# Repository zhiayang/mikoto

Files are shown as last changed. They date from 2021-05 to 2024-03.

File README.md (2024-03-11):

# みこと

nRF52840 microcontroller, in a pro-micro footprint, inspired by the [nRFMicro](https://github.com/joric/nrfmicro) and [nice!nano](https://nicekeyboards.com/nice-nano).

**See [the changelog](./CHANGELOG.md) for the revision history (and compatibility)**

### picture

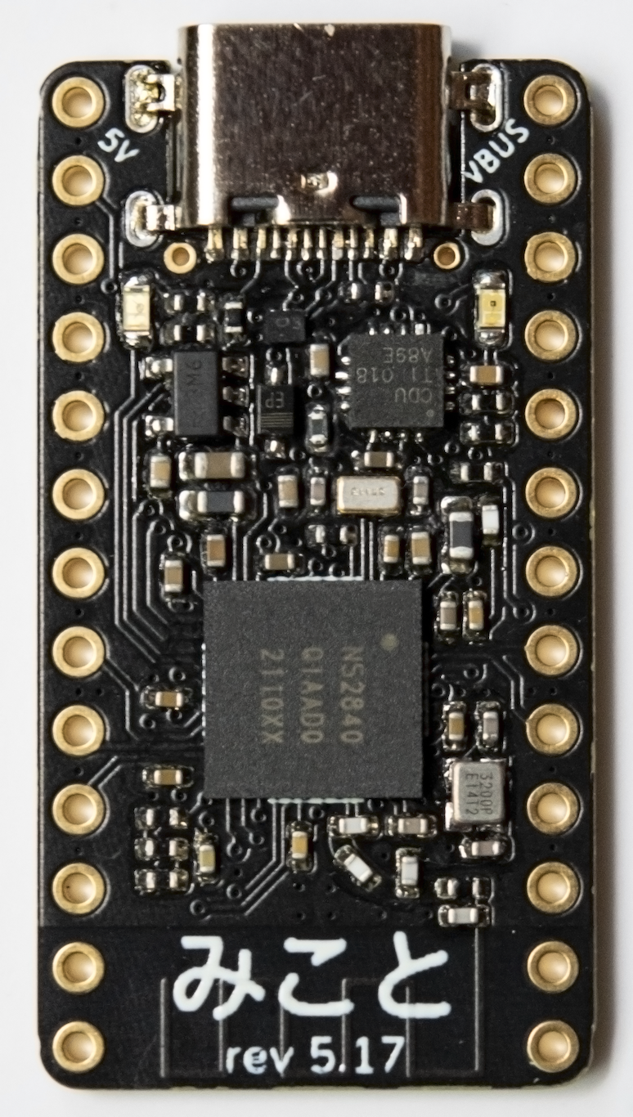
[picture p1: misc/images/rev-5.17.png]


### what

1. VDDH power path (5V USB power, and/or 3.7V Li-ion battery)
2. software controllable battery charge current (off, ~100mA, ~250mA, ~350mA)
3. ESD protection on USB lines, and 500mA fuse protection for VBUS and EXT_5V
4. "Bidirectional" power over EXT_5V

The charger IC is "software controlled"; there are two pins (P0.26 and P1.15) that can be toggled (for a total of 4 combinations) to control the charge current. If they are both high-Z (floated), is disabled.

There are also two additional through-holes (the small ones below the USB connector), marked **B** and **G** (on the back side); these are **B+** and **B-** respectively, in case you want to solder the battery leads directly to the board.

Note that the project files require KiCad 6.0.

### ext_5v

The EXT_5V pin acts both as a power input and a power output; normally it is an input. When VBUS is high (ie. USB is connected), it will output VBUS (minus a schottky drop, ~0.3V).

EXT_5V is connected to the battery charger, so if you wire your TRRS (for split keyboards) to it (instead of a 3.3V VCC line), you can charge the battery on both halves by only plugging in one half to USB.

### production & assembly

Since the design contains a controlled-impedance trace (namely the antenna feed), it is specific to a given stackup from a given
manufacturer. The current design files are optimised for JLCPCB's 1.6mm, 4-layer 7628 stackup.

**read**: if you choose to use a different (1) board thickness, (2) manufacturer, or (3) stackup, you ***must*** modify the design
accordingly to change the antenna feed (either trace width, plane separation, or both). The antenna feed uses a grounded coplanar waveguide design.

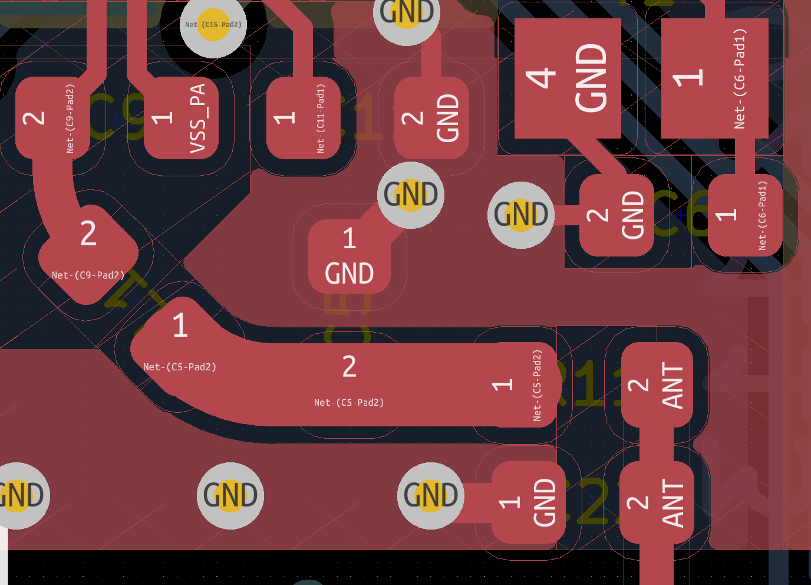
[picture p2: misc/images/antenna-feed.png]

<p align="center">Figure 1: the antenna feed</p>

The PCB *should* be manufactured with an ENIG surface finish, but it has been tested with HASL boards (run a solder wick over the pads first). All components are 0402 (1005 metric) or larger, and can be placed by hand without magnification. A stencil is mandatory — get a 100µm (0.1mm) thick one.

It's a good idea to get an electropolished stencil if you want to paste more than one board at a time, otherwise you will probably need to completely clean out the stencil before pasting another board.

All prototypes are assembled with Chipquik SMD291AX T4 solder paste.

There's no "component silkscreen" on the board except 4 lines to align the nRF chip, so use [`ibom.html`](./misc/ibom.html) while placing parts. It is generated using KiCad's excellent [Interactive BOM](https://github.com/openscopeproject/InteractiveHtmlBom) plugin.

### software

ZMK now has support for mikoto, as of [this PR](https://github.com/zmkfirmware/zmk/pull/985), and so does the *Adafruit nRF52 Bootloader*, as of [this PR](https://github.com/adafruit/Adafruit_nRF52_Bootloader/pull/230). Thanks to @mrninhvn for both of those. A binary version of the bootloader (0.6.3) can be found in `misc/bootloaders/`.

### license

Licensed under the Apache 2.0 license, see [LICENSE](./LICENSE).

If you encounter any problems, feel free to open an issue on this repo. However, I am *not obligated* to provide any support, and you undertake any assembly/manufacturing/purchasing **at your own risk**.

> on an **AS IS** BASIS, **WITHOUT WARRANTIES** OR CONDITIONS OF ANY KIND, either express or implied, including, without limitation, any warranties or conditions of TITLE, NON-INFRINGEMENT, MERCHANTABILITY, or FITNESS FOR A PARTICULAR PURPOSE.

> In **no event** and under no legal theory, ..., shall any Contributor be liable to You for damages, including any direct, indirect, special, incidental, or consequential damages of any character arising as a result of this License or out of the use or inability to use the Work.

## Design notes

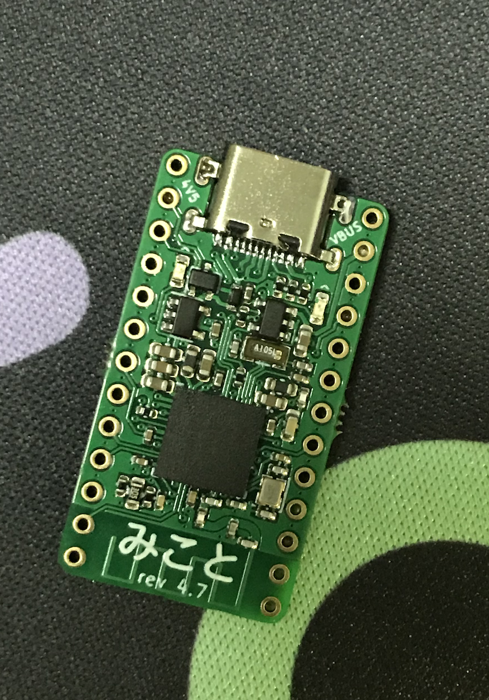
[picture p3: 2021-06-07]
misc/images/rev-4.7.png

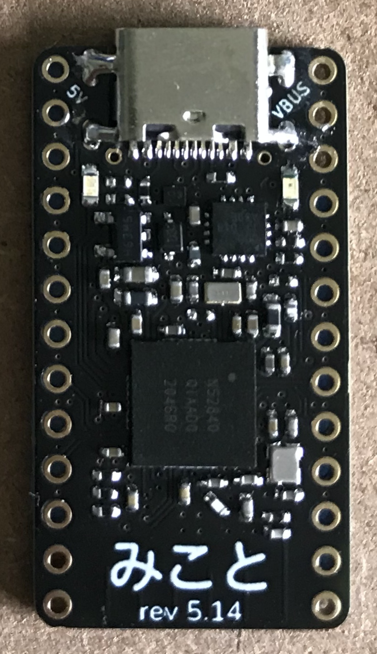
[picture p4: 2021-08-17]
misc/images/rev-5.14.png

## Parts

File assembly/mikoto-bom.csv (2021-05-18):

Comment | Designator | Footprint | LCSC Part #
4.7uF Unpolarized capacitor, small symbol | C1,C13,C14,C20,C21,C25 | C_0603_1608Metric | C19666
100nF Unpolarized capacitor, small symbol | C2,C3,C4,C10 | C_0402_1005Metric | C1525
1pF Unpolarized capacitor, small symbol | C5,C9 | C_0402_1005Metric | C1550
10pF Unpolarized capacitor, small symbol | C6,C7 | C_0402_1005Metric | C32949
1uF Unpolarized capacitor, small symbol | C8,C15,C23,C24 | C_0402_1005Metric | C52923
100pF Unpolarized capacitor, small symbol | C11 | C_0402_1005Metric | C1546
1nF Unpolarized capacitor, small symbol | C12 | C_0402_1005Metric | C1523
47nF Unpolarized capacitor, small symbol | C16 | C_0603_1608Metric | C1622
15pF Unpolarized capacitor, small symbol | C17,C18 | C_0402_1005Metric | C1548
10nF Unpolarized capacitor, small symbol | C19 | C_0402_1005Metric | C15195
1.5pF Unpolarized capacitor, small symbol | C22 | C_0402_1005Metric | C1552
BLUE Light emitting diode, small symbol | D1 | LED_0603_1608Metric | C72041
MSK4010 Schottky diode, small symbol | D2 | D_SOD-523 | C345958
ORANGE Light emitting diode, small symbol | D3 | LED_0603_1608Metric | C2286
logo_front Mounting Hole without connection | DUMMY1 | mikoto-logo
logo_back Mounting Hole without connection | DUMMY2 | mikoto-logo
mousebite_left Mounting Hole without connection | DUMMY3 | mouse-bite-2mm-slot-one-sided
mousebite_right Mounting Hole without connection | DUMMY4 | mouse-bite-2mm-slot-one-sided
USB_C_Receptacle_USB2.0 | J1 | USB-C_C168688
Conn_01x01 Generic connector, single row, 01x01, script generated (kicad-library-utils/schlib/autogen/connector/) | J2,J3 | 1pin_conn
3.9nH Inductor, small symbol | L1 | L_0402_1005Metric | C14033
15nH Inductor, small symbol | L2 | L_0402_1005Metric | C27143
10uH Inductor, small symbol | L3,L4 | L_0603_1608Metric | C1035
Net-Tie_2 Net tie, 2 pins | NT1 | net-tie-2-tiny
Net-Tie_2 Net tie, 2 pins | NT2,NT3 | net-tie-2-0.3mm
DMP2165UW P-MOSFET transistor, gate/source/drain | Q2 | SOT-323_SC-70 | C388477
1M Resistor, small symbol | R3 | R_0402_1005Metric | C26083
10M Resistor, small symbol | R4 | R_0402_1005Metric | C26082
1k Resistor, small symbol | R5,R8 | R_0402_1005Metric | C11702
100k Resistor, small symbol | R6 | R_0402_1005Metric | C25741
10k Resistor, small symbol | R7 | R_0402_1005Metric | C25744
5.1k Resistor, small symbol | R9,R10 | R_0402_1005Metric | C25905
3M Resistor, small symbol | R11 | R_0603_1608Metric | C23156
TestPoint test point | TP1,TP2,TP3 | TestPoint_Pad_1.0x1.0mm
TestPoint test point | TP4 | circular-pad-0.3mm
nRF52840 Multiprotocol BLE/ANT/2.4 GHz/802.15.4 Cortex-M4F SoC, AQFN-73 | U1 | Nordic_AQFN-73-1EP_7x7mm_P0.5mm | C190794
TP4054 Single cell, Li-Ion/Li-Po charge management controller, 4.20V, Tri-State Status Output, in SOT23-5 package | U2 | SOT-23-5 | C32574
AP2112K-3.3 600mA low dropout linear regulator, with enable pin, 3.8V-6V input voltage range, 3.3V fixed positive output, SOT-23-5 | U3 | SOT-23-5 | C51118
ProMicro_2 | U4 | akami-pins
32MHz Four pin crystal, GND on pins 2 and 4, small symbol | Y1 | Crystal_SMD_2016-4Pin_2.0x1.6mm | C254298
32.768 kHz Two pin crystal, small symbol | Y2 | Crystal_SMD_3215-2Pin_3.2x1.5mm | C32346

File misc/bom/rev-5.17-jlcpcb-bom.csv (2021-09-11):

Comment | Designator | Footprint | LCSC Part #
4.7uF Unpolarized capacitor, small symbol | C1,C13,C14,C20,C24,C25,C26 | Capacitor_0402_1005M-nosilk | C23733
100nF Unpolarized capacitor, small symbol | C2,C3,C4,C10 | Capacitor_0402_1005M-nosilk | C1525
1pF Unpolarized capacitor, small symbol | C5,C9 | Capacitor_0402_1005M-nosilk | C1550
15pF Unpolarized capacitor, small symbol | C6,C7,C17,C18 | Capacitor_0402_1005M-nosilk | C1548
1uF Unpolarized capacitor, small symbol | C8,C15,C23 | Capacitor_0402_1005M-nosilk | C52923
100pF Unpolarized capacitor, small symbol | C11 | Capacitor_0402_1005M-nosilk | C1546
1nF Unpolarized capacitor, small symbol | C12 | Capacitor_0402_1005M-nosilk | C1523
47nF Unpolarized capacitor, small symbol | C16 | Capacitor_0402_1005M-nosilk | C26403
10nF Unpolarized capacitor, small symbol | C19 | Capacitor_0402_1005M-nosilk | C15195
10uF Unpolarized capacitor, small symbol | C21 | Capacitor_0603_1608M-nosilk | C19702
1.5pF Unpolarized capacitor, small symbol | C22 | Capacitor_0402_1005M-nosilk | C1552
BLUE Light emitting diode, small symbol | D1 | LED_0603_1608Metric | C72041
ORANGE Light emitting diode, small symbol | D3 | LED_0603_1608Metric | C72038
PMEG4010CEJ Schottky diode, small symbol | D5 | D_SOD-323F-nosilk | C50704
500mA hold Resettable fuse, polymeric positive temperature coefficient, small symbol | F1 | Fuse_0402_1005Metric | C206938
USB_C_Receptacle_USB2.0 | J1 | USB-C_C168688 | C168688
3.9nH Inductor, small symbol | L1 | Inductor_0402_1005M-nosilk | C14033
15nH Inductor, small symbol | L2 | Inductor_0402_1005M-nosilk | C27143
10uH Inductor, small symbol | L3,L4 | Inductor_0603_1608M-nosilk | C1035
Net-Tie_2 Net tie, 2 pins | NT1 | net-tie-2-tiny
3.9k Resistor, small symbol | R1 | Resistor_0402_1005M-nosilk | C51721
2M Resistor, small symbol | R2,R3,R12 | Resistor_0402_1005M-nosilk | C138014
10M Resistor, small symbol | R4 | Resistor_0402_1005M-nosilk | C26082
1.5k Resistor, small symbol | R5 | Resistor_0402_1005M-nosilk | C25867
10k Resistor, small symbol | R6,R7,R8 | Resistor_0402_1005M-nosilk | C25744
5.1k Resistor, small symbol | R9,R10 | Resistor_0402_1005M-nosilk | C25905
0R Resistor, small symbol | R11 | Resistor_0402_1005M-nosilk | C17168
nRF52840 Multiprotocol BLE/ANT/2.4 GHz/802.15.4 Cortex-M4F SoC, AQFN-73 | U1 | AQFN-73-1EP_7x7mm_P0.5mm_NRF52840-custom | C1851953
BQ24075/9 USB-Friendly Li-Ion Battery Charger and Power-Path Management | U2 | VQFN-16-1EP_3x3mm_P0.5mm_EP1.6x1.6mm | C15464
XC6220B331MR 1A, Low Drop-out Voltage Regulator, Fixed Output 3.3V, SOT-23-5 | U3 | SOT-23-5 | C86534
mikoto-pins | U4 | mikoto-pins
ESDR0502NMUTAG | U5 | UDFN-6_1.2x1.0mm_P0.4mm | C327480
32MHz Four pin crystal, GND on pins 2 and 4, small symbol | Y1 | Crystal_SMD_2016-4Pin_2.0x1.6mm | C255896
32.768 kHz Two pin crystal, small symbol | Y2 | Crystal_SMD_2012-2Pin_2.0x1.2mm | C93231

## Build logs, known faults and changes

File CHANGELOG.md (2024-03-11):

# changelog

Note that numbers are skipped arbitrarily based on my whims and fancies.

## revision 7.2 (untested)

Previous revision: 7.1

Compatibility:

- Pinout identical to 6.3
- New stencil required (different from 7.1)

Changes:

1. remove I2C pullups from MAX17048 chip; they were frying the MCU IO pins
2. shrink LEDs to 0402 size
3. add solder points for metal can

## revision 7.1 (do not build -- broken)

Previous revision: 6.3

Compatibility:

- Pinout identical to 6.3
- New stencil required

Changes:

1. add on-board MAX17048 fuel gauge IC for battery monitoring

## revision 6.3

Previous revision: 6.1

Compatibility:

- (Slightly) incompatible pinout: `VDDH` pin (top right) changed to `VDD`
- Stencil / position / parts compatible with 5.17+
- Underside pads compatible with 6.1

Changes:

1. Change the `VDDH` extra pin to be `VDD` instead; note that it's usually an output, and should only draw a maximum of 25mA (less when transmitting!)
2. Fiddle slightly with the antenna layout (with ref. to the nRF52840 Dongle from Nordic) even though I don't know what I'm doing
3. Adjust trace routing around the antenna feed to improve ground plane coverage

## revision 6.1

Previous revision: 5.20

Compatibility:

- Incompatible pinout, bottom pad layout for USB changed (SWD pad positions unchanged).
- Stencil / position / parts compatible with revisions 5.17 - 5.20.

Changes:

1. Changed `P1.00` to `P1.08` (still high drive)
2. Exposed the old `P1.00` as an `SWO` pad instead (useful for debug trace output)
3. Changed the `VBUS` pin to expose `VDDH` instead
4. `VBUS` exposed as an underside pad

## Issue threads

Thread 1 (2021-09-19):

can it use nice！nano firmware directly？

SAIXX, 2021-09-19:
If there are some differences with that when re-flash the bootloader?

zhiayang, 2021-09-19:
you can use the nice!nano v2 bootloader directly. firmware-wise, there is no official ZMK shield.

Closed 2021-10-05.

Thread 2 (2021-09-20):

Why there's a voltage regulator in the design?

marekpiechut, 2021-09-20:
Hi.

Sorry for opening an issue, but found no better place to get in touch with you.

I'm studying the design, and while most of the stuff makes sense for me, I don't get why do you have an external voltage regulator there. It seems that you're powering the battery charger module directly from USB and then connect it directly to VDDH on the MCU. It looks like regulated voltage is only being used to output it on pin 22 of Pro-Micro compatible pins and it's not really needed for the board to work.

Am I right, or am I missing something?
Thanks for help.

zhiayang, 2021-09-21:
yes, that's right. the LDO is only to power external stuff (eg. LEDs, displays, etc.) on whatever you attach the mikoto to, and not used for anything on-board.

Closed 2021-09-21.

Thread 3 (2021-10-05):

Hi , has you simulated the antenna signal  in HFSS ?

xiaoquanaa, 2021-10-05:
Hi , has you simulated the antenna signal  in HFSS ?

zhiayang, 2021-10-05:
no, i have not.

xiaoquanaa, 2021-10-05:
so does it works well as a keyboard mcu?

xiaoquanaa, 2021-10-05:
> no, i have not.

so does it works well as a keyboard mcu?

zhiayang, 2021-10-05:
the bluetooth radio works well. i have not written the firmware for it yet, but you can get zmk working without too much effort.

xiaoquanaa, 2021-10-07:
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
Hi , i can't understand that why p0.14 and p0.16 i named "reset" , isn't a default reset pin p0.18?

Closed 2021-10-12.

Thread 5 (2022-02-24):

BLE has no service

ImMrMa, 2022-02-24:
Hi, thank you so much for sharing your mikoto repo, I printed the mikoto pcb and loader zmk software in the pcb. But I can't connect the hid ble sevice, seems the ble signal has no advertised service

zhiayang, 2022-02-25:
i can't tell if this is a hardware problem or a software issue (with zmk). are you able to load up a simpler firmware (eg. just something that makes a BLE beacon) and see if the antenna works?

check the component placement and soldering as well. which revision did you print?

ImMrMa, 2022-02-25:
I use the revision 5.20 for print. And flash the bootloader and zmk you mentioned. Are there any recommended programs to flash just for test the ble.

zhiayang, 2022-02-25:
you can get get bluemicro board support package for nrf52840, and use something like this https://learn.adafruit.com/bluefruit-nrf52-feather-learning-guide/advertising-beacon to test it out

ImMrMa, 2022-02-26:
I recheck my bom list. found that I use 32mhz 8pf as the crystal rather than 32mhz 12.5pf you used. Is this the main reason？I try to replace a 12.5pf crystal on it.

zhiayang, 2022-02-26:
that could be the possible culprit; afaik the HF crystal is used for timing bluetooth packets, so if the capacitance is out of spec then the frequency could deviate enough that bluetooth won't work.

you can either replace the crystal, or replace the load capacitors with something that'll work for a 8pf crystal.

ImMrMa, 2022-03-05:
After replace the crystal, I finally successfully connect to the board by ble!
Thanks for you help !!!

Closed 2022-03-05.

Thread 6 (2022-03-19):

What to choose for layer stackups and other choices for PCB manufacturing?

Ardakilic, 2022-03-19:
Hello,

I want to try this board, but I'm lost at ordering step.

While ordering from JLCPCB, what do I have to choose for these layer stackup choices?

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

An example screenshot or list of choices would have been awesome. Even with providing the stackups, I can't enable the SMT assembly, it's telling me to reset the order.

Thanks in advance!

zhiayang, 2022-03-20:
L1 = F_Cu
L2 = In1_Cu
L3 = In2_Cu
L4 = B_Cu

Stackup = JLC7628

As for assembly, I don't know if they have stock of all the chips (notably the charging IC and MCU itself). Last time I checked you're also limited to green PCBs for 4-layer assembly.

Ardakilic, 2022-03-20:
Thanks for this. Finally I could pass these parameters. I just wish JLC did not cost $265 for 5 PCB's BOM, and this is even missing nRF52840 itself!

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

I'll definitely buy the PCBs and stencil, and source the parts in the future by myself.

Thanks again!

zhiayang, 2022-03-21:
heck, that is really expensive. it'll be very hard to place/solder the MCU (basically impossible) once the other parts are populated though, so getting it assembled at JLC is usually all-or-nothing.

Closed 2022-03-20.

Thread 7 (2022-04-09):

why short reset pin with a GPIO pin?

DoudouMee, 2022-04-09:
- I dont understand why connect reset pin (P0.18/RESET) to P0.14 and P0.16. These 3 GPIO are completely shorted together.
- If I change the schematic and free them up, can I use they 3 pins as GPIO without short P0.18/RESET to any other pin?

> 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

zhiayang, 2022-04-09:
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

there is no other way to get the reset pin out from under the chip.

DoudouMee, 2022-04-09:
> 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
>
> there is no other way to get the reset pin out from under the chip.

soga! So, in fact I dont need a high voltage on  (P0.18/RESET) when this Soc starting up?

zhiayang, 2022-04-09:
no, the reset pin has an internal pullup on nRF chips.

DoudouMee, 2022-04-10:
I see, thanks a lot.

Closed 2022-04-10.

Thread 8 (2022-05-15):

board not work after flashing zmk uf2

ImMrMa, 2022-05-15:
Hello, Zhiayang
I have some confuse in develop my own board.
I follow your schema designed my board with fpc interface and ceramic anatenna.
I successfully tested the board in circuit python that both BLE and HID are work well with your bootloader.
But after flash your mikoto zmk build uf2 file, my computer couldn't find the hid keyboard signal through usb.
Could you give me some advice on problems (like def in pins or others) may cause the zmk program not working.
More details:
when I set bootloader mode or flash the circuit python uf2, the crystal has 0.869v.
After I flash the zmk uf2, the crystal only has 0.15~0.3v.
It make me confused.
Best Wishes

ImMrMa, 2022-05-15:
Ok, finally I found that I lost a 10uH inductance in the schema.
After I disable the dcdc mode in zmk, the program work well.
Thank you so much!

Closed 2022-05-15.

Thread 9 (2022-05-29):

Any specific reason for the incompatible pinout?

Miigon, 2022-05-29:
It seems like the current pinout of mikoto isn't really compatible with nice!nano or promicro-based keyboard pcb. The top most pins on the left and right side are EXT_5V and VDD_NRF instead of B- and B+, and VBAT is connected to where RAW would be on a pro micro. I wonder is this a deliberate design choice?

Because of the different battery pinout, mikoto can't really be used as a drop-in replacement for a nice!nano. Instead requiring the keyboard pcb to be specifically designed for and only for mikoto. (aka connecting battery to RAW). But that would render the keyboard incompatible with any other pro micro compatible microcontroller since most controllers connect VBUS to RAW, which meant they will SEND 5V DIRECTLY TO THE BATTERY if used on a pcb designed for mikoto.

(Unfortunately I have to find out about the incompatible pinout the hard way by distroying 2 of my mikoto boards (dead nrf52840) because the battery tried to send too high of a voltage to what it thought was B+ but actually is VDD_NRF. 😢)

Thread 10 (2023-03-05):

Device don't connect

admfgonzalez, 2023-03-05:
Hi zhiayang, first of all thank you very much for sharing your design with the community :). I sent to make some mikoto 6.3 to JLCPCB and they finally arrived, but I can't configure them, I may have done something wrong in the order process, especially with the orientation of the components. I'm not very good with electronics, could you help me identify what I did or what I'm doing wrong? Thank you very much in advance for your help. The microcontroller
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

zhiayang, 2023-05-25:
Sorry the super delayed response. Unfortunately I can't really help with this, it might be a manufacturing issue

Tworck, 2023-12-12:
Hey @admfgonzalez

Ultimately we are unsure what the problem is. The yellow light is constantly on and no connection to the microcontroller is made via usb

Did you figure out the issue to your problem. We believe that we have the same issue.

One thing that we notices is the orientation of the Y1 Oscillator.

We also used
https://www.farnell.com/datasheets/1562852.pdf

which states that connector 2 and connector 4 should be connected to GND. Which seems to be correct for the component we used. see image.

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

Kicad shows it in the same way.

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

So technically this should be correct. Maybe the issue is somewhere else.

zhiayang, 2023-12-13:
does the board show up over SWD? there's solder pads on the back you can use to connect to a stlink, and maybe try flashing firmware/bootloader with adafruit-nrfutil or openocd.

if it shows up over SWD, i would check the usb data lines for shorts (there's pads on the back too in case the connector pins are too small).

actually -- you guys *did* flash the bootloader, right? I don't think the usb connection will do anything (certainly it won't show up as a usb drive) until you do.

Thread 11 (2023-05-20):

Battery charging

djbutler, 2023-05-20:
I am trying to use Mikoto with a 3.7V 400mAh lithium ion polymer battery (https://www.adafruit.com/product/3898). I am setting the charging current to 100mA in software. But charging does not seem to work correctly: as I understand it, the battery is supposed to charge to about 4.2V, but it often gets stuck between 3V and 3.5V. It seems like perhaps the precharge phase is working, but not the fast charge phase. (See: https://www.ti.com/lit/ds/symlink/bq24075.pdf).

Is there a battery that is known to charge correctly with this circuit?

zhiayang, 2023-05-25:
I've only used no-name batteries from aliexpress, and they appear to work from my own testing. Are you setting the charge current via the driver in ZMK?

djbutler, 2023-05-28:
I'm actually running the `nice!nano` build of CircuitPython, and just setting pins P0.26 and P1.15 manually with `digitalio.DigitalInOut`:

```
en1 = digitalio.DigitalInOut(board.P0_26)
en1.direction = digitalio.Direction.OUTPUT
en1.value = False

en2 = digitalio.DigitalInOut(board.P1_15)
en2.direction = digitalio.Direction.INPUT
en2.pull = None
```

My understanding was that setting a pin as an input would produce a high-impedance state. But perhaps I'm doing this incorrectly.

Thanks for your feedback.

zhiayang, 2023-06-10:
yes, this should have worked. I'm not sure why it's not working, though. It might be some incompatibility somewhere, but I can't really help with just this much to go on.

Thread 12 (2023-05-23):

Wasn't sure how to reach out;

WainingForests, 2023-05-23:
Hey! I'm looking to mesh this design into something that incorporates JST SH connectors. I have a reasonably mediocre understanding of pcb design especially when it comes to signaling design.
Headers should be easy enough.

What I don't know if I can do for sure is if I can pull out 1 or 2 more extra pins. It looks like I "might" be able to pull them out via one of the internal layers. But I realize there is alot of considerations going on with your design and I don't want to end up breaking things more than I'm helping them.

Thoughts?

zhiayang, 2023-05-25:
Extra pins as in from the nRF chip itself? I'm not sure if there's space for that, but feel free to try. As for design considerations:

1. try not to split the ground plane on layers 2 and 3, because there isn't enough space for too many stitching vias
2. I can't remember if there's a power plane on layer 3 under the chip itself; if there is, then you definitely don't want to split it. The alternative is to get rid of the plane (if it exists) and just route power manually with thick traces.
3. As long as the modifications don't go near the antenna area, it should be fine :D

WainingForests, 2023-05-30:
Thanks by the way for the response! I've been "trying" and seem reasonably successful! I did have one question. Can you think of a way to have 3.3v output from battery that CAN'T be shut of by pin13?

I'd like to be able to toggle LEDS while not killing a trackball / trackpad / Shift register.

zhiayang, 2023-06-10:
Probably not, if it needs to be exactly 3.3v

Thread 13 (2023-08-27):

resistor R12 (2M) does not appear in file gerber

hvuitsme, 2023-08-27:
I checked that the Top designator part doesn't show the 2M(R12) resistor and I can't fix it

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

hvuitsme, 2023-08-27:
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

zhiayang, 2023-08-28:
since I did not provide the BOM and pick-and-place file (BOM/CPL), I don't think I can help you here.

hvuitsme, 2023-08-29:
I got the prototype in your repository
[mikoto-top-pos.csv](https://github.com/zhiayang/mikoto/files/12459930/mikoto-top-pos.csv)

Bomb file is still the same with this pos file

zhiayang, 2023-08-29:
how did you generate this file? some of the parts (like R12) are missing rotation values. that seems to be the problem.

cscott, 2024-02-07:
You should probably use the JLC Fabrication Toolkit plugin, available from KiCad's plug-in manager, to generate the production files.

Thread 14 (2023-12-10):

Questions about the power path

pymo, 2023-12-10:
Hi, sorry for raising an issue for this topic, but I don't find other ways to reach out.

I am making a keyboard PCB with the WCH CH582F chip, and I find your schematic a good reference for the power path part. However, there are some design questions I hope you can help me understand:

1. You seem to replace the TP4054+LDO with the BQ24075 in later revisions, what is the consideration? My MCU is 3.3V so I want to go with the TP4054+LDO solution, but I don't know if there are any disadvantages of it.

2. How necessary are the ESD Protection Diodes on D+/D-? Did you add them because you see damages happening without it?

3. You seem to replace the Schottky barrier diode from PMEG2010AEB to PMEG4010CEJ, what is the consideration? Is it OK to use a 1N5819WS instead?

Thanks in advance!

zhiayang, 2023-12-11:
1. the nrf52840 can do HV mode which uses the internal DC-DC voltage converter, which is more efficient than an LDO so in theory saves a bit of battery. otherwise you'd have to use LDO to step 3.7v battery to 3.3v.
2. just in case. it's the most frequently "touched" part, feels weird not to have esd
3. 2010 was too small (SOD523) for my old eyes, 4010 has SOD323 which is a little bigger.  i just chose a diode with a small Vf drop.

pymo, 2023-12-11:
Thanks a lot! Those answers are very helpful!

Closed 2023-12-11.

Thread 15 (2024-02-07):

PCB thickness

cscott, 2024-02-07:
The README says:
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

And indeed you specify the manufacturer and stackup -- but I don't think the README ever explicitly specifies the correct board thickness to use?  Reading between the lines (and looking at the KiCad setup) it /seems/ to be the "standard" 1.6mm board thickness, but it would be nice to explicitly say so in the README (if that's right).

Thanks so much for your board!  I'm hacking on it to use for a Ploopy Mini trackball, and it's a great timesaver to have working KiCad files for start with.

zhiayang, 2024-02-07:
oh, yep -- it's meant to be 1.6mm. I'll add that, thanks!

Closed 2024-02-07.

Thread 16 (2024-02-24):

Changelog for 7.1

alexmaloteaux, 2024-02-24:
Hi
Is there any relevant changelog for 7.1 , compared to 6.3 ?
Thanks

zhiayang, 2024-02-26:
thanks for reminding me, i'll update the doc in the next few days. the main difference is the on-board fuel gauge ic.

zhiayang, 2024-03-05:
welp, i screwed up rev 7.1, so the changelog isn't important.

zhiayang, 2024-03-11:
updated

Closed 2024-03-11.

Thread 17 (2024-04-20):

Can not use KiKit automation

ton-im, 2024-04-20:
If use KiKit automation , KiCAD will show error as pic1 .
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
Because of the file mikoto.kicad_pcb have 6 wrong lines , 11335-11340 . These lines add nothing .
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
Delete these lines , KiKit will work well .

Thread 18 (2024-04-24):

pinmux.c, purpose of gpio_pin_set(p0,3,0)

yangxing844, 2024-04-24:
hi, in the pinmux.c which is the file source used to control the charge current, what is the purpose of gpio_pin_set(p0,3,0), in the schematic, the pin is not connected, why would we do anything with it?

yangxing844, 2024-04-24:
sorry, that was a mistake of global substitute, closing now

Closed 2024-04-24.

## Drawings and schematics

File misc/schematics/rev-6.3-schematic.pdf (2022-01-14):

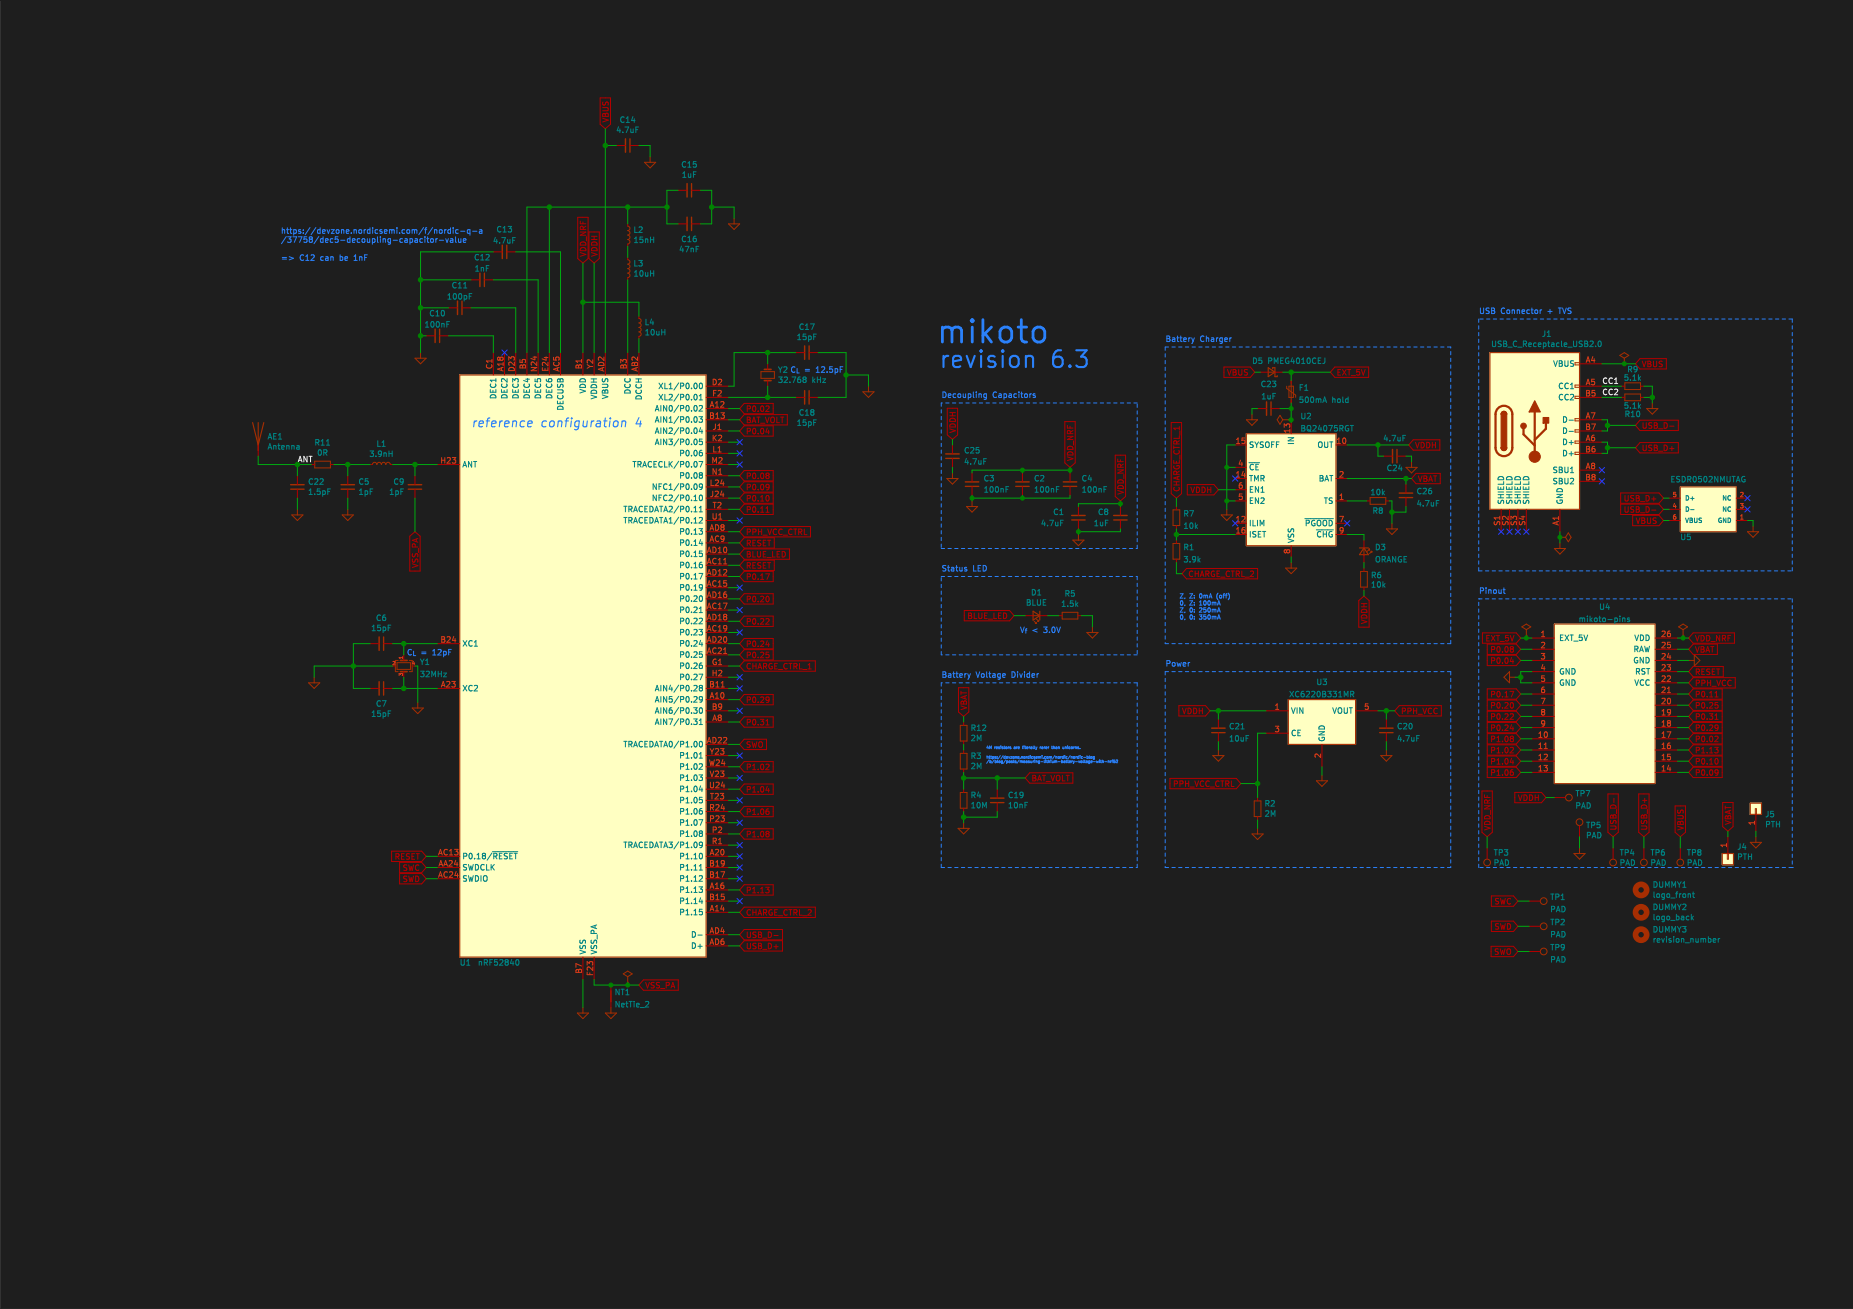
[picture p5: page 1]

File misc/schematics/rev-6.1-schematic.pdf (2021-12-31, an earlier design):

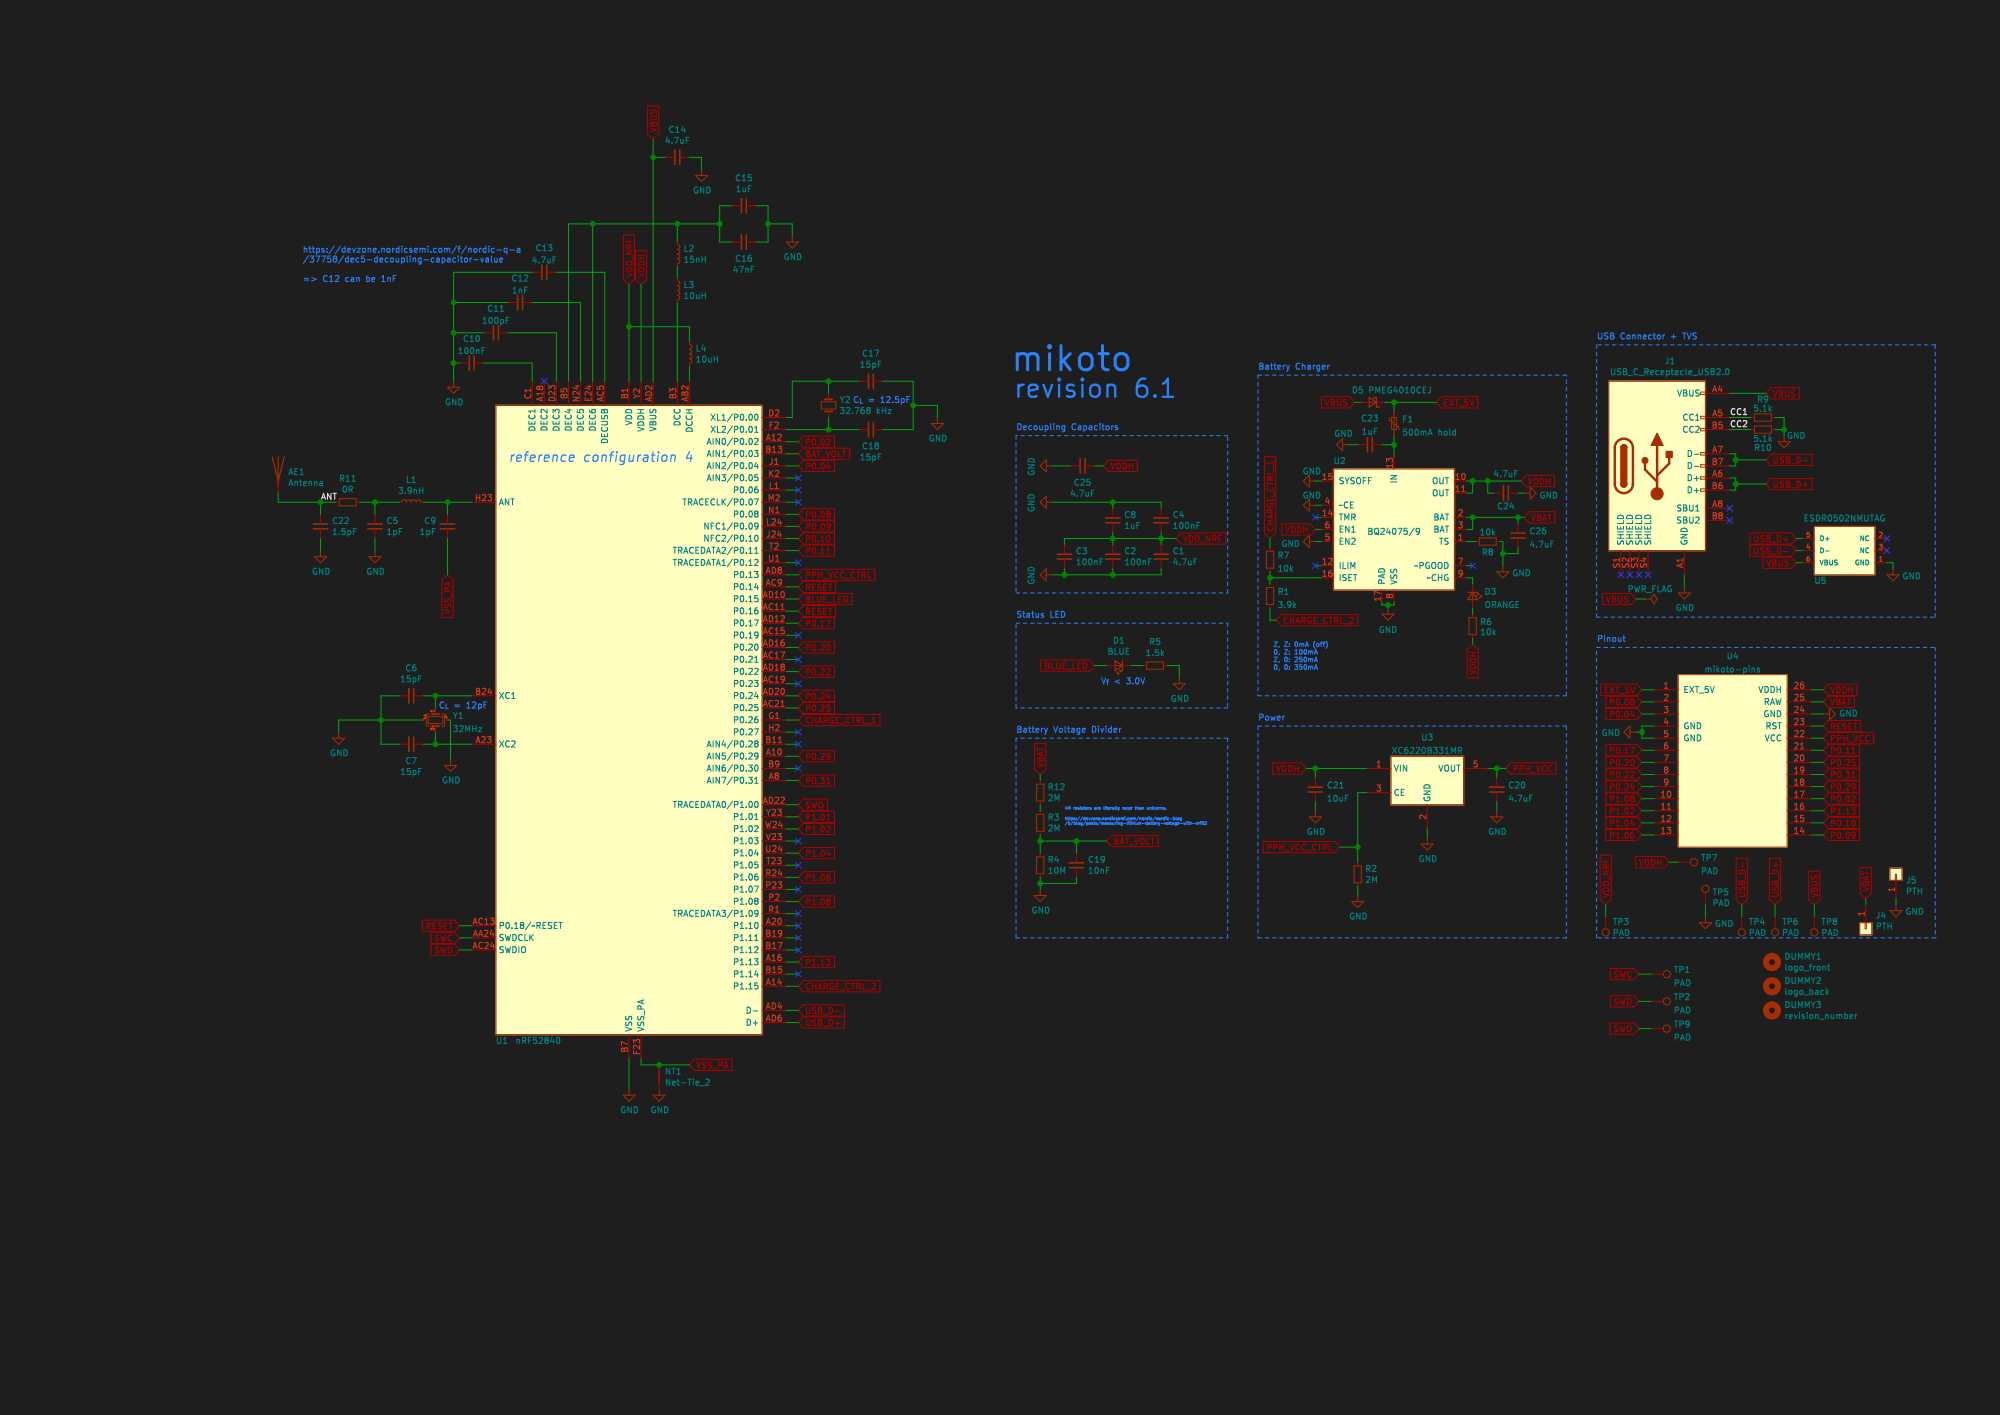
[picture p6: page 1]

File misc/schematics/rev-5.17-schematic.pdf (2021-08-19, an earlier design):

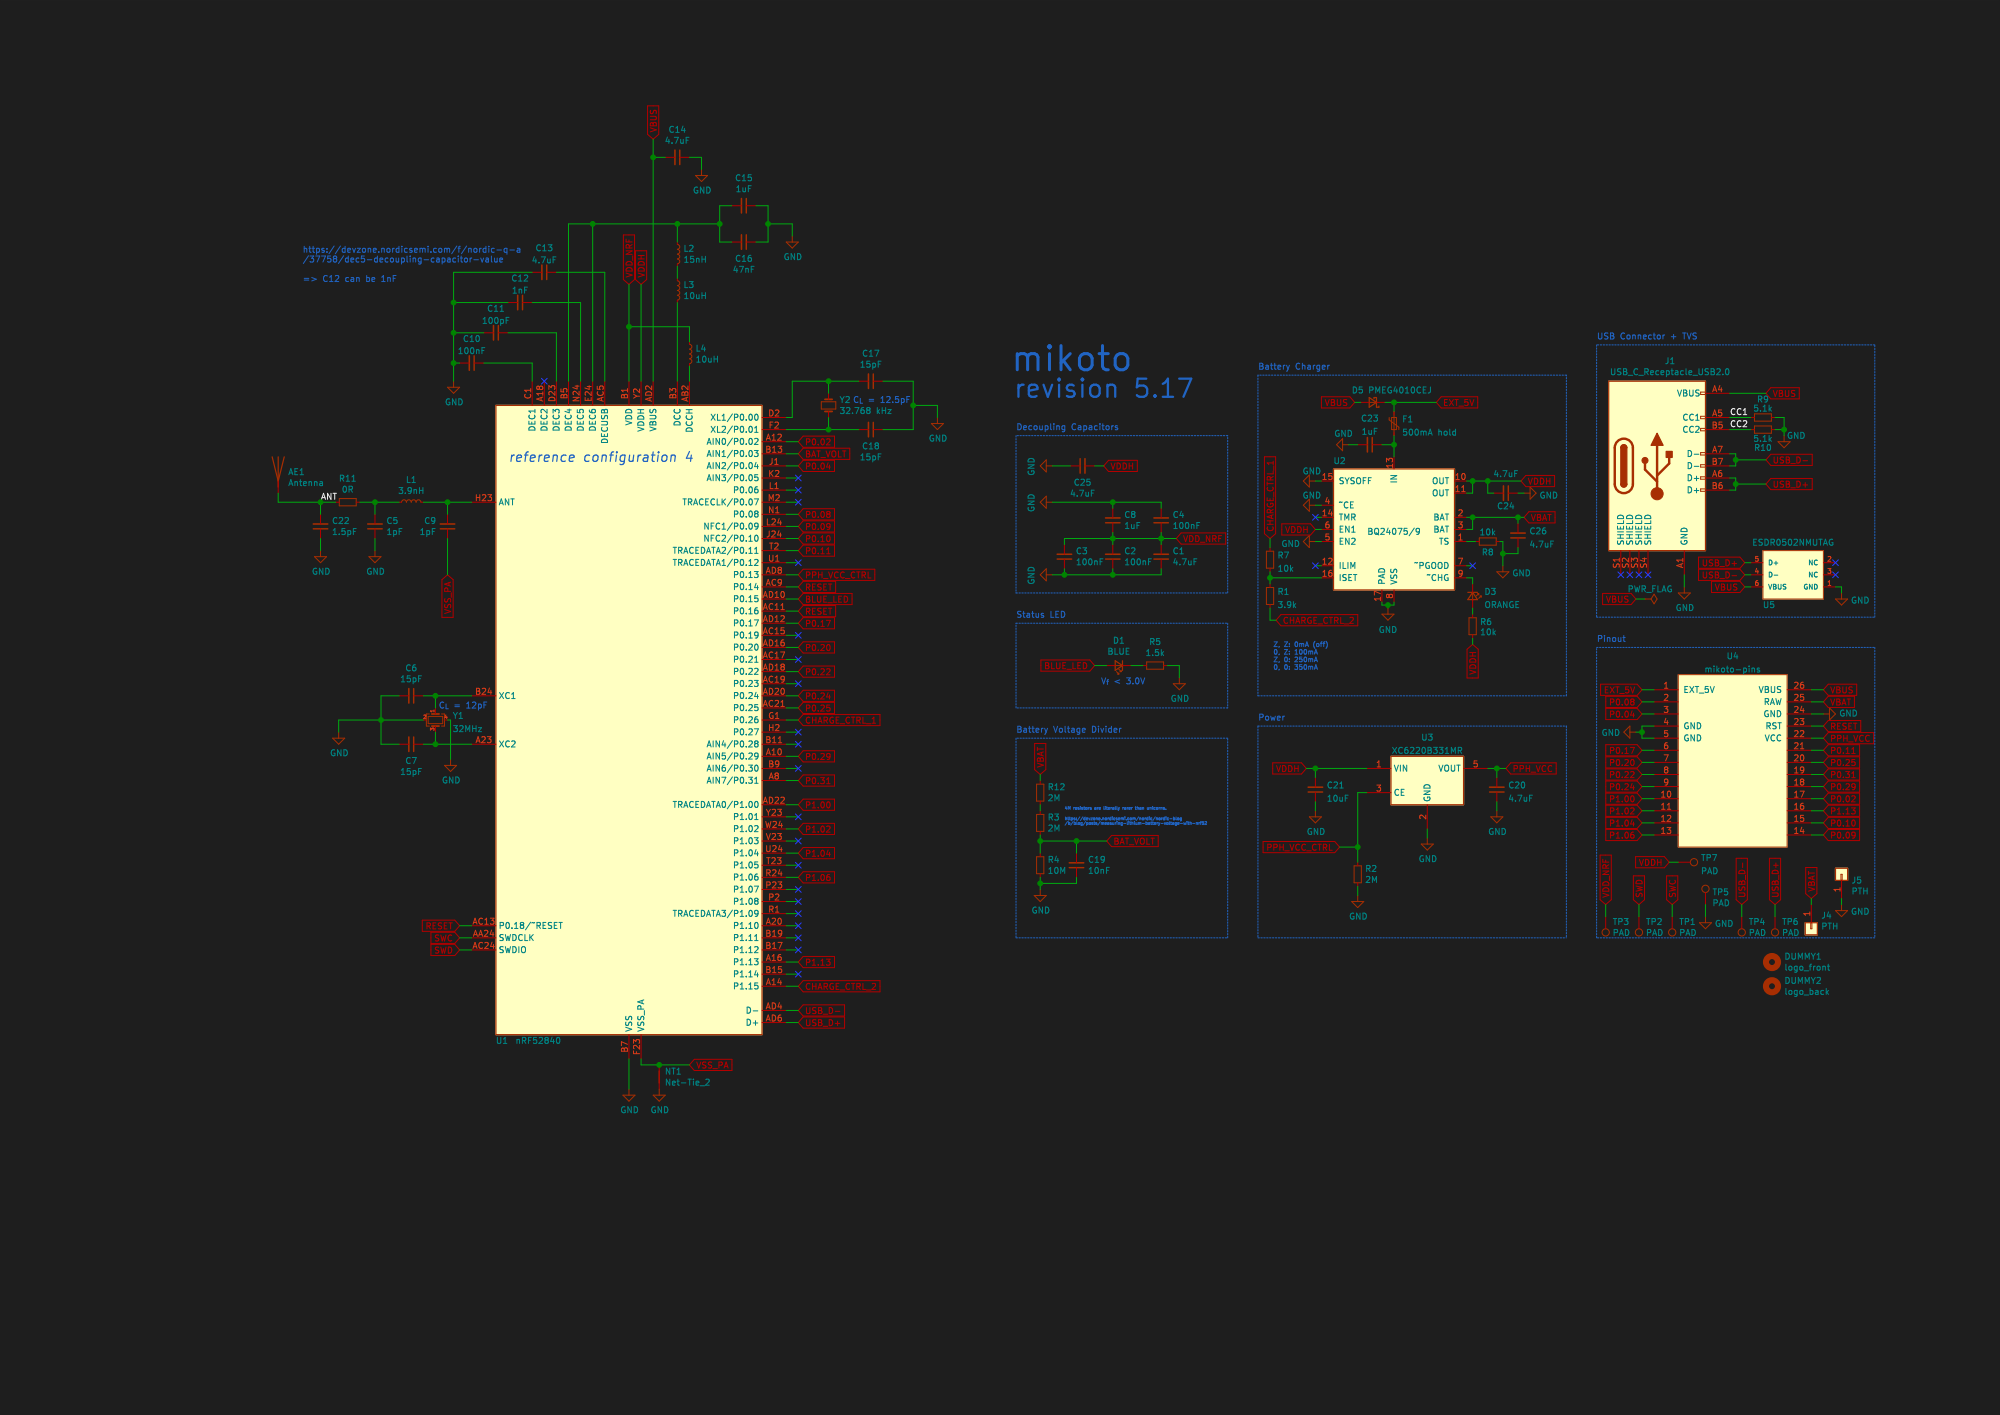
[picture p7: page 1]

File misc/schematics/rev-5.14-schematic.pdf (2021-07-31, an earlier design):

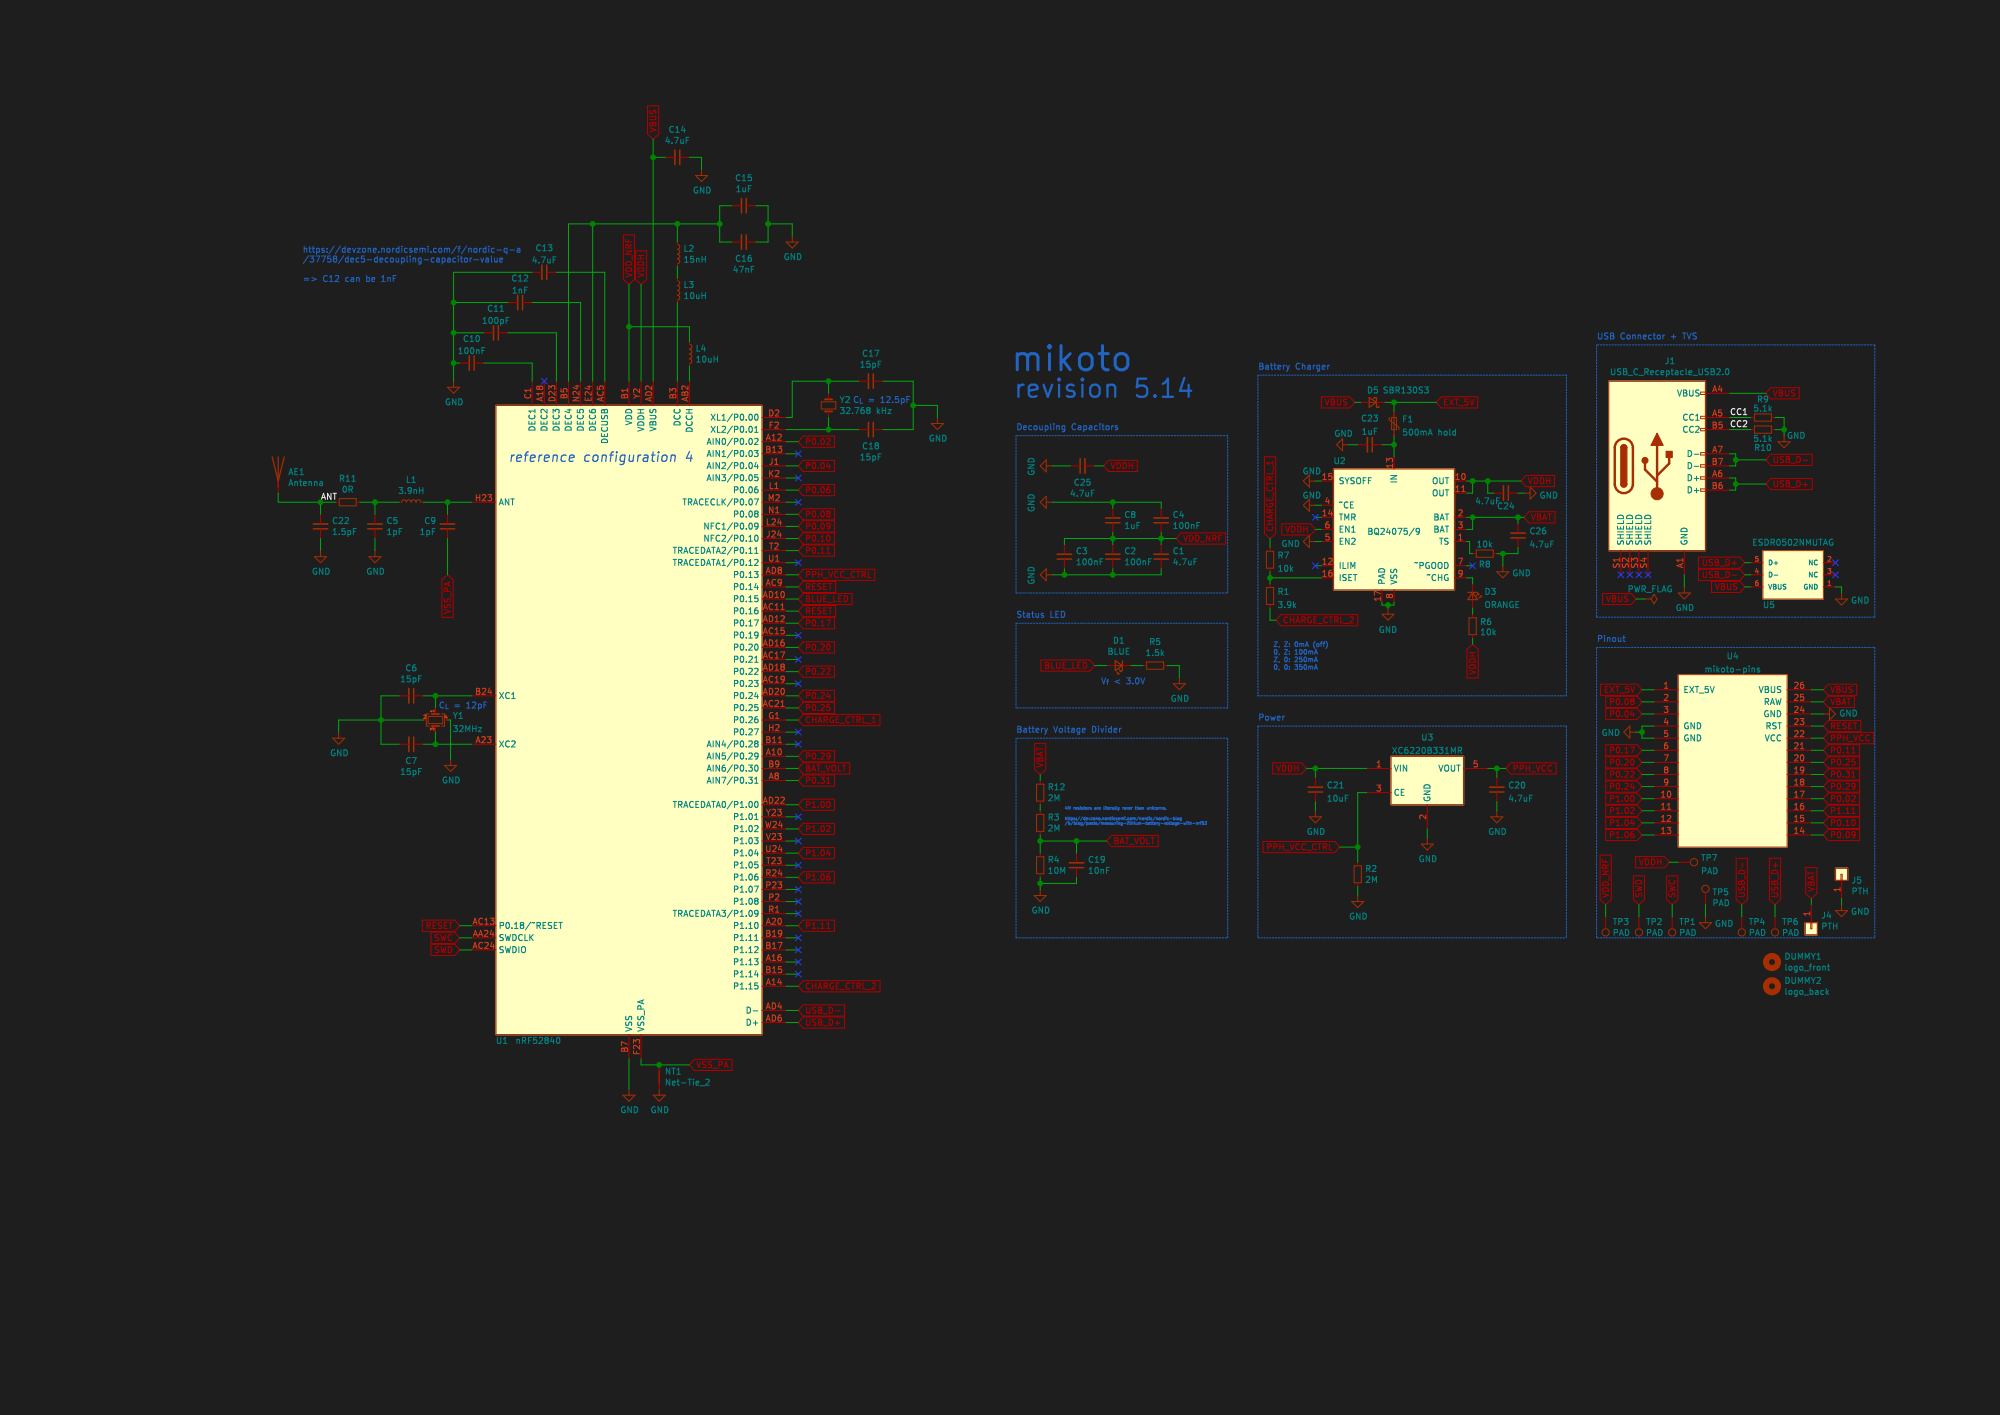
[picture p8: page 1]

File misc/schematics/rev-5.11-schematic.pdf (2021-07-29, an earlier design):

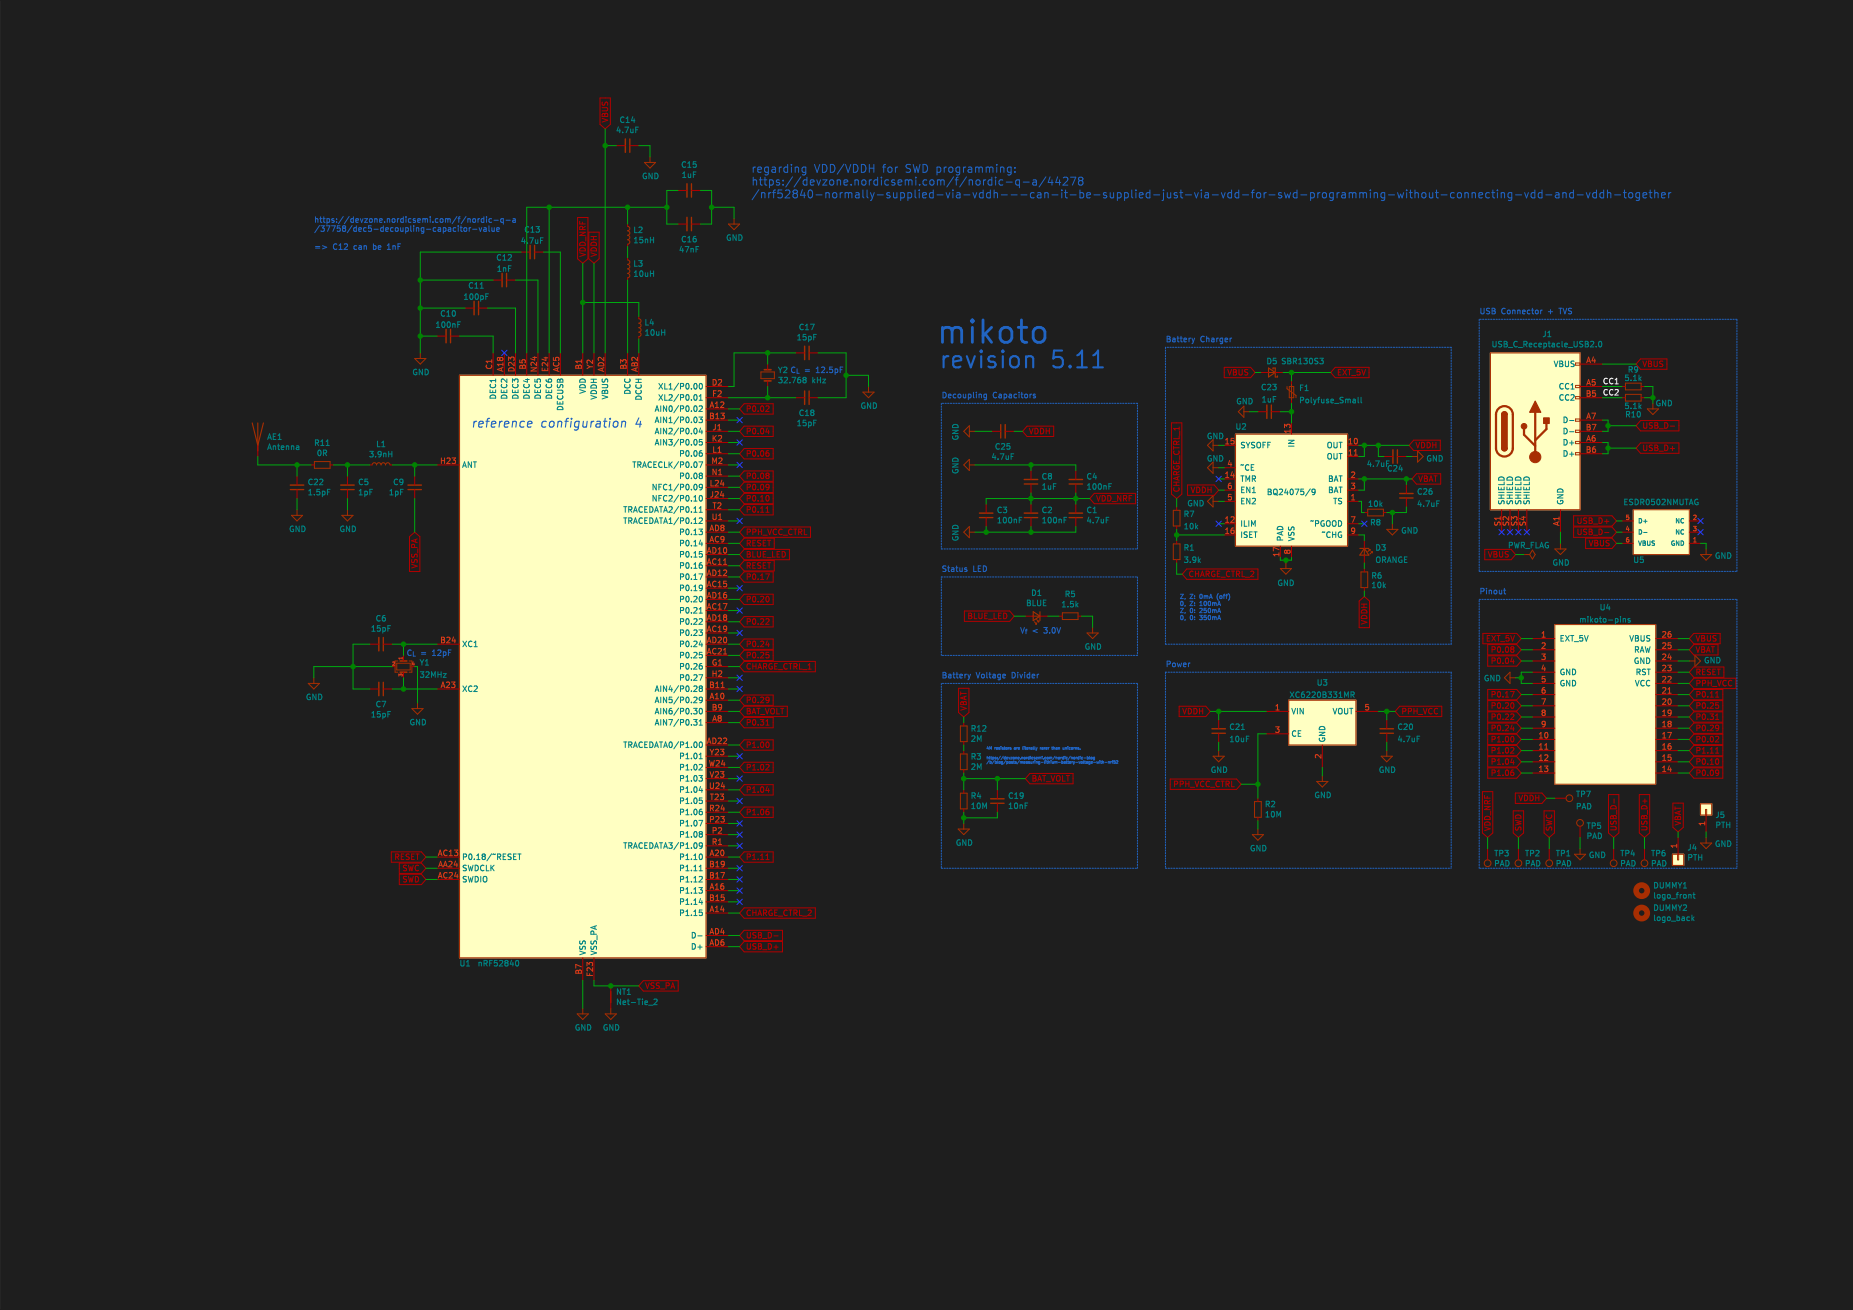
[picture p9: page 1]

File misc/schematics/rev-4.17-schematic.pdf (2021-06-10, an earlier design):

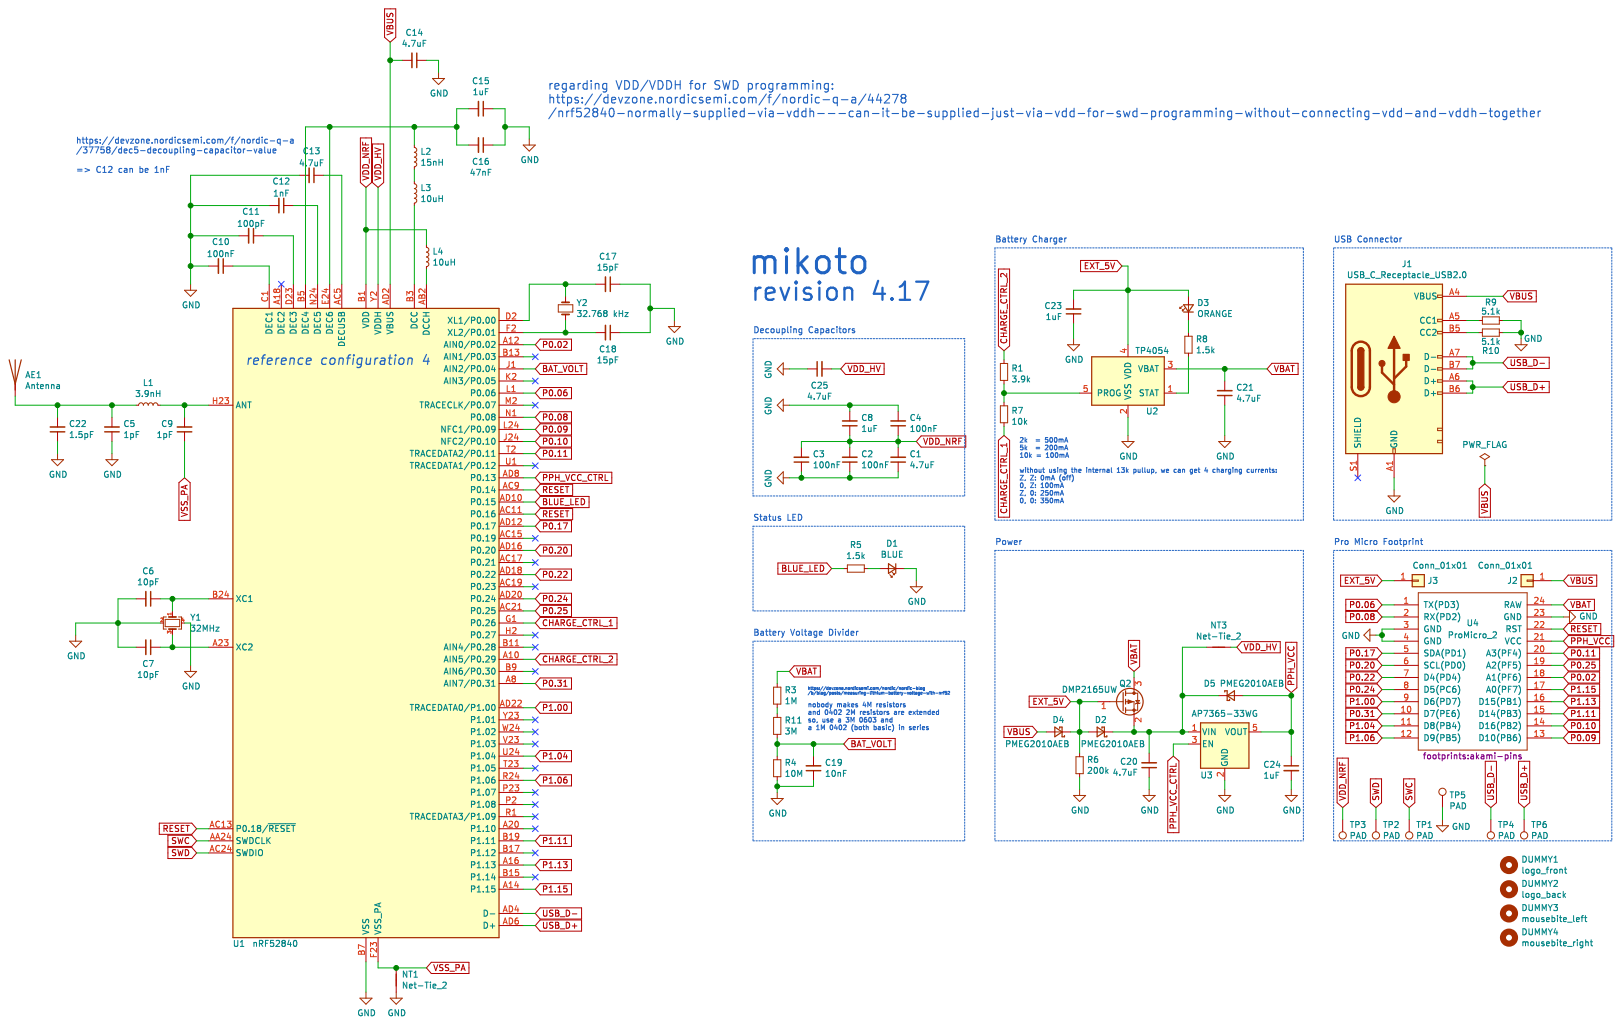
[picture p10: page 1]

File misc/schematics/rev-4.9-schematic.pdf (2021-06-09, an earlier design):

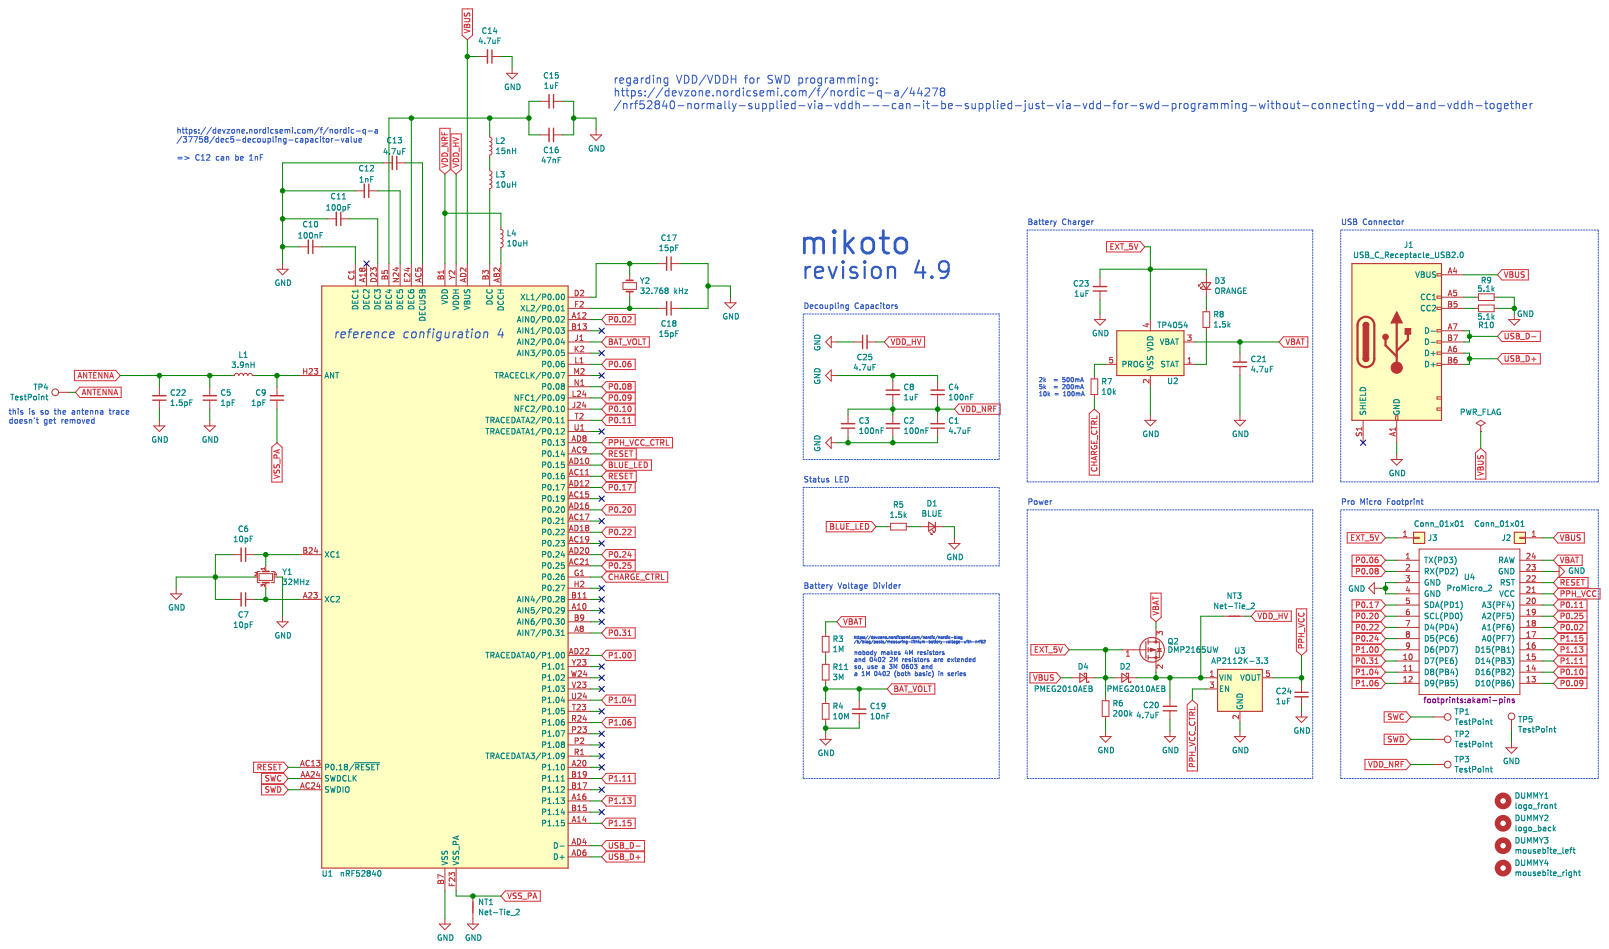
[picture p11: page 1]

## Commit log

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2021-01-07 add (experimental) rev 2, using VDDH (high voltage) input.
    other things (related to switching to VDDH):
    1. get rid of the power control mosfet; now uses the LDO (AP2112K)
    and its EN control to control EXT_VCC
    2. related to (1), power output is now OFF by default -- drive the
    pin high to enable VCC out.
    3. add a schottky diode (D4) to protect the LDO from reverse flow,
    while also letting current from EXT_VCC (eg. TRRS) drive the MCU
    and also any peripherals. (note that the driving side then can't
    disable peripheral [eg. OLED, EEPROM] power, for obvious reasons)
    4. switch the schottky diode (D2) to a 1N5817 (from 819) to shrink
    the BOM, due to (3).
    5. break out both VDDH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
    [akami-B_Cu.gbl, akami-B_Cu.gbr, akami-B_Mask.gbr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]
2021-01-07 update gerbers and bom/pos
    [akami-B_Cu.gbr, akami-B_Mask.gbr, akami-B_Paste.gbr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]
2021-01-08 minor: rearrange the schematic a bit
    [akami-B_Cu.gbr, akami-B_Mask.gbr, akami-B_Paste.gbr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]
2021-01-20 rev 2.1 (hv): 1. remove the 1M pulldown on the LDO enable pin; AP2112K has an internal pull-down already. 2. adjust pcb layout/routing slightly.
    [akami.kicad_pcb, akami.sch]
2021-01-20 rev 2.2 (hv): 1. remove the diode connecting EXT_VCC to VDD_HV; pending further investigation on how to improve the power path.
    [akami.kicad_pcb]
2021-01-20 rev 2.3 (hv): 1. replace AP2112 LDO with LP5912; it's some weird SMD package but it's only 2x2mm; 500mA max output and 30uA quiescent. it's not like we'll be the ones soldering it anyway.
    2. similarly, replace 1N5817 schottkys with MSK4010 schottkys; it's
    SOD-523, so even smaller than the 323s.
    3. move the components at the top a little further away from the
    USB port, since that has to be hand-soldered.
    that freed up a bunch of space to hopefully try some stuff with the
    power path.
    note: gerbers/BOM/PnP files not updated
    [akami.kicad_pcb, akami.sch]
2021-01-20 rev 3A (lv): preliminary circuit
    it's basically the original low-voltage circuit, but with another
    mosfet to control the second EXT pin, with a schottky in parallel
    to reduce Vf across the mosfet.
    it should work, but it's sad that it has to be low voltage. it also
    requires an additional extended part for a smaller footprint mosfet
    because no way can we fit 3 SOT-23s on the board currently.
    [akami.sch]
2021-01-21 continue placement and routing on 3A
    [akami.kicad_pcb, akami.sch]
2021-01-21 rev 3 (lv): 1. layout and route all components
    2. replace mosfet pullups with 1M resistors
    3. silkscreen pin labelling now shows nRF52 pin numbers instead
    of promicro pins (those are "standard" and hence useless to
    print)
    4. VBUS and EXT_VCC is now broken out; VBUS is coincidentally in
    the same place as an Elite-C (above RAW -- now BAT)
    gerbers, BOM, and PnP files *are* updated.
    [akami-B_Cu.gbr, akami-B_Mask.gbr, akami-B_Paste.gbr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]
2021-01-24 rev 3.1 (lv):
    1. move the antenna down slightly.
    2. adjust thermal spoke fill parameters on the front copper
    around the transmission line.
    [akami.kicad_pcb]
2021-01-29 rev 3.2
    1. re-layout and re-route the entire thing
    2. as part of (1), move the nrf chip up by 0.75mm
    3. add a 1uF capacitor on the VBUS input to the charger IC
    4. move components further away from the USB connector since that
    has to be hand-soldered
    [akami-B_Cu.gbr, akami-B_Mask.gbr, akami-B_Paste.gbr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]
2021-05-18 rev 4.0
    1. Switch to the VDDH (high voltage) power path
    2. External power is now 3V3 (PRH) and 4V5 (EXT_5V).
    due to the diode, we are forced to drop ~500mv from VBUS
    3. Swap the positions of VBUS and EXT_VCC. This makes us not quite
    compatible with eg. Elite-C, but that was just a bonus anyway.
    4. Switch back to the AO3401A mosfet
    [mikoto.kicad_pcb, mikoto.sch]
2021-05-18 rev 4.1
    Swap P0.11 and P0.31
    [mikoto.kicad_pcb, mikoto.sch]
2021-05-18 rev 4.2
    Replace P0.29 with P0.25
    [mikoto.kicad_pcb, mikoto.sch]
2021-05-18 rev 4.3
    1. (re)-swap VBUS and EXT_5V, so we are back to the original layout
    2. change the power plane copper fill to be VBUS for the top half
    [mikoto.kicad_pcb, mikoto.sch]
2021-05-18 rev 4.7
    1. replace exotic LP5912 LDO with more common AP2112K
    2. replace AO3401A mosfet with DMP2165UW (smaller package)
    [mikoto-B_Cu.gbr, mikoto-B_Mask.gbr, mikoto-B_Paste.gbr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]
2021-05-18 rev 4.7 -- add gerbers and pos/bom
    [mikoto-B_Cu.gbr, mikoto-B_Mask.gbr, mikoto-B_Paste.gbr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]
2021-05-19 update to kicad 5.99 format
    [mikoto.kicad_pcb, mikoto.kicad_sch]
2021-06-08 rev 4.8
    1. fix power path; hopefully this lets EXT_5V, VBUS, and VBAT all coexist
    2. replace MSK4010 diode with superior PMEG2010AEB (same footprint, less Vf)
    3. increase VBUS/EXT_5V pulldown to 200k, since it's now on the power path
    4. change LED resistors to 1.5k so it doesn't blind people
    5. add ground pad to the back (to complement VDD, SWD, SWC)
    6. split the upper power plane between VBUS and EXT_5V; may help
    power dissipation on the slave side
    7. change charging LED to yellow. don't like red.
    no gerbers/bom.
    [mikoto-copy.kicad_pcb, mikoto.kicad_pcb, mikoto.kicad_sch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]
2021-06-08 rev 4.9:
    1. move SWD/SWC pads further apart
    2. remove redundant routing to ext_5v and vbus since there's a power plane
    3. fix the silkscreen pin numbers
    4. move the pads up by 0.01mm...
    [mikoto.kicad_pcb, mikoto.kicad_sch]
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2021-06-09 add rev info to schematic; add empty wks file to repo
    [mikoto.kicad_sch]
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2021-06-09 rev 4.11
    1. add another resistor to the TP4054 Rprog pin (in parallel), so we can
    select between 3 charge currents (or off) with 2 pins
    2. change the antenna trace to be a proper footprint which is hopefully
    less accident-prone
    3. adjust the mousebites so hopefully they leave less material after breaking
    [mikoto.kicad_pcb, mikoto.kicad_sch]
2021-06-09 rev 4.11 -- slightly improve routing
    [mikoto.kicad_pcb]
2021-06-10 rev 4.12
    1. add a diode from PPH_VCC to VDD_HV; this should allow powering
    the non-usb board on splits for keyboards that send VCC over the
    TRRS (ie. anything not misaka)
    2. improve routing; shrink the charger IC output cap from 0603 to 0402
    3. switch AP2112K to AP7365WG; 20uA lower quiescent current, same pinout
    [mikoto.kicad_pcb, mikoto.kicad_sch]
2021-06-10 rev 4.15
    1. add underside pads for USB data lines
    2. adjust the position of the USB connector a little
    [mikoto.kicad_pcb, mikoto.kicad_sch]
2021-06-10 rev 4.17
    1. remove the power plane fill "outside" the pin headers, since those
    aren't connected well to the main VDD plane
    [mikoto.kicad_pcb, mikoto.kicad_sch]
2021-06-10 rev 4.17: add gerbers, assembly files (BOM/CPL), and schematic
    [mikoto-B_Cu.gbr, mikoto-B_Mask.gbr, mikoto-B_Paste.gbr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]
2021-06-13 update flashbed and add gerbers
    [mikoto-flashbed.kicad_pcb, mikoto-flashbed.kicad_sch]
2021-06-22 rev 4.19: add two small PTHs for soldering battery wires.
    [mikoto.kicad_pcb, mikoto.kicad_sch]
2021-06-22 update to kicad nightly r22971
    [mikoto.kicad_pcb, mikoto.kicad_sch]
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2021-07-20 wip-5.0: initial schematic & bom
    [mikoto.kicad_sch]
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2021-07-21 clean up front silk
    [mikoto.kicad_pcb]
2021-07-21 remove thermal reliefs from SMD pads
    [mikoto.kicad_pcb]
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2021-07-22 rev 5.3
    1. go back to thermal reliefs for the top half (ie. non-RF section)
    2. switch to SBR diodes (SOD-323) that hopefully have less
    reverse current leakage.
    3. slighly change pinout so we expose 3 analogue pins in total
    [mikoto.kicad_pcb, mikoto.kicad_sch]
2021-07-22 rev 5.4
    add TVS protection (ESDR0502N) on USB and VBUS lines
    [mikoto.kicad_pcb, mikoto.kicad_sch]
2021-07-23 rev 5.7
    improve routing; add VDDH plane and remove EXT_5V plane. also,
    add a polyfuse on EXT_5V.
    [mikoto.kicad_pcb, mikoto.kicad_sch]
2021-07-27 rev 5.9
    1. change the fuse so it protects against VBUS as well. the diode is
    rated for 1A so the fuse will trip before that fries anyway
    2. change P0.06 to P0.04, giving us one more ADC pin (that's also
    normal/high drive)
    [mikoto.kicad_pcb, mikoto.kicad_sch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]
2021-07-27 rev 5.11
    1. move thermal vias for bq24075 to not be literally under the paste
    2. reduce the EP paste for the nrf52 (and place the vias between the
    paste islands)
    3. remove all silks for passives because it's ugly
    4. fix the incorrect pin labelling (since we switched P0.06 to P0.04)
    [mikoto-flashbed.kicad_pcb, mikoto-flashbed.kicad_sch, mikoto.kicad_pcb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]
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2021-07-29 some nonsense with the flashbed
    [mikoto-flashbed.kicad_pcb, mikoto-flashbed.kicad_sch]
2021-07-29 minor changes to paste layer; no revision bump
    [mikoto.kicad_pcb]
2021-07-29 rev 5.11
    minor tweaks to RF placement. no revision bump.
    [mikoto.kicad_pcb, mikoto.kicad_sch]
2021-07-31 rev 5.14
    change LDO pulldown to 2M. tweak routing and other small things.
    [mikoto-flashbed.kicad_pcb, mikoto.kicad_pcb, mikoto.kicad_sch]
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2021-08-18 rev 5.17
    1. flip C25 around so the grounds don't align
    2. change P1.11/1.10 to P1.13 (silkscreen also changed)
    3. replace SBR130S3 with PMEG4010CEJ (SOD-323F) (+ footprint)
    4. move signals away from under the L3 inductor
    [mikoto.kicad_pcb, mikoto.kicad_sch]
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2021-08-19 rev 5.17(b): fiddle with trace widths, change BAT_VOLT pin
    move BAT_VOLT to P0.03, since it makes for a shorter trace.
    make all traces on the nRF chip either 0.15mm or 0.20mm; this might
    reduce the chance of soldering failure on the USB pins. maybe.
    [mikoto.kicad_pcb, mikoto.kicad_sch]
2021-08-22 rev 5.19
    improve inner plane filling, add keepout on power plane below
    32kHz crystal.
    [mikoto.kicad_pcb, mikoto.kicad_sch]
2021-09-03 rev 5.20
    shrink the paste (again) on U1 and U2 (nrf and bq24075)
    [mikoto.kicad_pcb, mikoto.kicad_sch]
2021-09-03 fix silkscreen for charger IC. no revision bump
    [mikoto.kicad_pcb]
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
